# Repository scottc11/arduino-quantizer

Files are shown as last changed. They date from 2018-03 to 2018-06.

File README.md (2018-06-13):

## LIBRARIES / DEPENDENCIES

#### [Adafruit MPR121](https://learn.adafruit.com/adafruit-mpr121-12-key-capacitive-touch-sensor-breakout-tutorial/overview)
- [eagle files can be found here](https://learn.sparkfun.com/tutorials/mpr121-hookup-guide)
#### [MCP4725 DAC](https://www.adafruit.com/product/935)

---
## QUANTIZER LOGIC

The QUANTIZER needs to output a single voltage relative to the last `touched` or `selected` (via voltage input)

The currently active notes will be toggled on / off via the touch sensors.

There is one touch sensor and one toggle switch for each `TONIC`.  Each `TONIC` will have a state equal to `major`, `minor`, `augmented`, and `diminished`. The state of each `TONIC`will be determined by their respective toggle switches.

The `Vout` will be determined depending on which `MODE` the quantizer is in:

`OUT MODE`: The last touched sensor
  - does not require `Vin`

`ARP MODE`:
  - the 'quantized' `Vin`
  - LEDs represent active notes `Vin` should be quantized to
  - does require `Vin`

Modular synths tend to follow a scheme were a specific change in voltage – such as 1.00 volts – results in a precisely one octave change in pitch. In a 1 volt per octave scheme, 1/12 of a volt change results in a semitone change in pitch.

```
5.00v == 5 octaves == 4095
1.00v == 1 octave == 819
0.08333v == half-tone == 68.25
0.16666v == whole-tone == 136.5
```

MCP4725 Library accepts input as a uint_t value between  0 to 4095

```
I    --> 1.0v ------>  819
II   --> 1.16666v -->  955.5
III  --> 1.33332v -->  1092
IV   --> 1.41665v -->  1160.25
V    --> 1.58331v -->  1296.75
VI   --> 1.74997v --> 1433.25
VII  --> 1.91663v --> 1569.75
VIII --> *2.0v    --> 1638

* round up to make perfect octave
```

### Quantization of `Vin` to `activeNotes`:
divide number of activeTonics by 1023. This will give you the thresholds for each note. Copy these thresholds to an array, from lowest to highest.
```

int activeCount = 0;
int activeNotes[];
int thresholdArray[];

for (int i=0; i<arrLength; i++) {
  if (activeTonics[i] == true) {
    activeNotes[activeCount] = quantizedVoltages[i];
    activeCount += 1;
  }
}
int threshold = 1023 / activeCount;
for (int i=0; i<activeCount; i++) {
  thresholdArray[i] = threshold * (i + 1);
}

for (int i=0; i<activeCount; i++) {
  if (Vin < thresholdArray[i]) {
    Vout = activeNotes[i];
  }
}
```

### Moog Werkstatt Calibration

Connect `Vout` of quantizer into the `VCO EXP IN` on the moog werkstatt.  You will have to remove the front panel of the werkstatt and modify the trimmer labelled `VCO EXP TRIM` so that 1.0v and 2.0v coming from `Vout` will make a perfect octave.  Use a tuner for this calibration.

---
# Arduino Programming Practices

#### Things to Note:
- Arduino code is essentially C/C++
- using dictionaries is pretty much out of the question due to memory limits

#### constants vs variables

constants don't take up valuable RAM space (the pre-processor subs the values in where needed), whereas variable declarations do.

```
// constants
#define VALUE_A 3
#define VALUE_B 1

// variables
int value_a = 3;
int value_b = 1;
```

#### [Charlieplexing](https://en.wikipedia.org/wiki/Charlieplexing)
- LED matrix
- Toggle Switch Matrix

---

# [I2C](https://learn.sparkfun.com/tutorials/i2c)

- I2C requires a mere two wires, like asynchronous serial, but those two wires can support up to 1008 slave devices.
- most I2C devices can communicate at 100kHz or 400kHz.
- It can be fairly trivially implemented in software.

#### Signals
- Each I2C bus consists of two signals: SCL and SDA. SCL is the clock signal, and SDA is the data signal.

---

# [Bitwise Operators](https://www.arduino.cc/reference/en/language/structure/bitwise-operators/bitwiseand/)
- One of the most common uses of bitwise AND is to select a particular bit (or bits) from an integer value, often called masking.
- [BitMath Tutorial](http://playground.arduino.cc/Code/BitMath)

In Arduino, the type int is a 16-bit value, so using & between two int expressions causes 16 simultaneous AND operations to occur.

```
int a =  92;    // in binary: 0000000001011100
int b = 101;    // in binary: 0000000001100101
int c = a & b;  // result:    0000000001000100, or 68 in decimal.
```
Each of the 16 bits in `a` and `b` are processed by using the bitwise AND, and all 16 resulting bits are stored in `c`, resulting in the value `01000100` in binary, which is `68` in decimal.

#### Common Bitwise Uses
- Saving memory by packing up to 8 true/false data values in a single byte.
- Turning on/off individual bits in a control register or hardware port register.
- Performing certain arithmetic operations involving multiplying or dividing by powers of 2.

###### Bitwise NOT operator

Bitwise NOT changes each bit to its opposite: 0 becomes 1, and 1 becomes 0. For example:
```
int a = 103;    // binary:  0000000001100111
int b = ~a;     // binary:  1111111110011000 = -104
```

###### Bit Shift Operators --> `>>` or `<<`
There are two bit shift operators in C++: the left shift operator `<<` and the right shift operator `>>`. These operators cause the bits in the left operand to be shifted left or right by the number of positions specified by the right operand. For example:
```
int a = 5;        // binary: 0000000000000101
int b = a << 3;   // binary: 0000000000101000, or 40 in decimal
int c = b >> 3;   // binary: 0000000000000101, or back to 5 like we started with
```
When you shift a value x by y bits (x << y), the leftmost y bits in x are lost, literally shifted out of existence.

### Port registers of the Atmega8

```
void setup()
{
  // set pins 1 (serial transmit) and 2..7 as output,
  // but leave pin 0 (serial receive) as input
  // (otherwise serial port will stop working!) ...
  DDRD = B11111110;  // digital pins 7,6,5,4,3,2,1,0

  // set pins 8..13 as output...
  DDRB = B00111111;  // digital pins -,-,13,12,11,10,9,8

  // Turn off digital output pins 2..7 ...
  PORTD &= B00000011;   // turns off 2..7, but leaves pins 0 and 1 alone

  // Write simultaneously to pins 8..13...
  PORTB = B00111000;   // turns on 13,12,11; turns off 10,9,8
}
```

Sometimes you might need to set multiple output pins at exactly the same time. Calling `digitalWrite(10,HIGH);` followed by `digitalWrite(11,HIGH);` will cause pin 10 to go `HIGH` several microseconds before pin 11, which may confuse certain time-sensitive external digital circuits you have hooked up. Alternatively, you could set both pins high at exactly the same moment in time using `PORTB |= B1100;`

------

### Button / Switch Logic

###### [Polling vs interrupts](http://www.martyncurrey.com/switching-things-on-and-off-with-an-arduino/)

<b>`Polling`</b> is where we are always checking the status of something. Inside the `loop()` function we continuously check the pin state with digitalRead(). We do not know if the pin state has changed until we look at it.

`Interrupts` is where the current process is interrupted and a new process is performed (the Arduino reacts to a pin state whether or not it is being checked). This means the code does not need to worry about the pin until the Arduino tells us to.

##### Turn LED On/Off with push button

```
int previousButtonState = LOW;

void loop() {
  int currentButtonState = cap.touched() & (1 << 0);

  if (currentButtonState == HIGH && oldButtonState == LOW) {
    // Switch the state of the output
    digitalWrite(ledPins[0], !digitalRead(ledPins[0]) );
  }

  previousButtonState = currentButtonState;
}
```

---

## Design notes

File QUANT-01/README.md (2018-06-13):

### Components

- [SPDT Toggle Switch](https://www.digikey.ca/product-detail/en/e-switch/200MSP1T1B1M2QEH/EG2447-ND/378916)
- Arduino Pro Mini
- MPR121 Touch Matrix
- MCP4725 DAC
- LED x 8

# MODES

- when switching between modes, you have to somehjow preserve the previous modes active notes
- one way to do this is to store monophonic mode last touched Vout in a variable, and arpeggiator modes last count + active notes.

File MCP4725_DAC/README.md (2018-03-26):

## [MCP4725 DAC](https://www.adafruit.com/product/935)

- [tutorial](https://learn.adafruit.com/mcp4725-12-bit-dac-tutorial)
- The output voltage is rail-to-rail and proportional to the power pin so if you run it from 3.3V, the output range is 0-3.3V. If you run it from 5V the output range is 0-5V.

#### Wiring

- connect `VDD` to your microcontroller power pin (3-5V), `GND` to ground, `SDA` to I2C Data (on the Arduino Uno, this is `A4`), `SCL` to I2C Clock(on the Arduino Uno, this is `A5`) and listen on `VOUT`.

- `A0` allows you to change the I2C address. By default (nothing attached to A0) the address is hex `0x62`. If `A0` is connected to `VDD` the address is `0x63`.
- `VOUT` is the voltage out from the DAC! The voltage will range from 0V (when the DAC value is 0) to VDD (when the DAC 'value' is the max 12-bit number: `0xFFF`)

---

#### [Adafruit MCP4725 Library](https://github.com/adafruit/Adafruit_MCP4725)

There is only one function that comes with the Adafruit MCP4725 Library, and it is pretty strait forward. In works with Arduino's `Wire` library so you must also import that at the top.

Essentially the function accepts a number between `0` and `4095` which gets evaluated into the Voltage out.  So passing `2500` will give you exactly `3.14V` on the `Vout` pin of the DAC.

```
/**************************************************************************/
/*!
   @brief  Sets the output voltage to a fraction of source vref.  (Value
           can be 0..4095)
   @param[in]  output
               The 12-bit value representing the relationship between
               the DAC's input voltage and its output voltage.
   @param[in]  writeEEPROM
               If this value is true, 'output' will also be written
               to the MCP4725's internal non-volatile memory, meaning
               that the DAC will retain the current voltage output
               after power-down or reset.
*/
/**************************************************************************/

void Adafruit_MCP4725::setVoltage( uint16_t output, bool writeEEPROM )
{
#ifdef TWBR
 uint8_t twbrback = TWBR;
 TWBR = ((F_CPU / 400000L) - 16) / 2; // Set I2C frequency to 400kHz
#endif
 Wire.beginTransmission(_i2caddr);
 if (writeEEPROM)
 {
   Wire.write(MCP4726_CMD_WRITEDACEEPROM);
 }
 else
 {
   Wire.write(MCP4726_CMD_WRITEDAC);
 }
 Wire.write(output / 16);                   // Upper data bits          (D11.D10.D9.D8.D7.D6.D5.D4)
 Wire.write((output % 16) << 4);            // Lower data bits          (D3.D2.D1.D0.x.x.x.x)
 Wire.endTransmission();
#ifdef TWBR
 TWBR = twbrback;
#endif
}
```

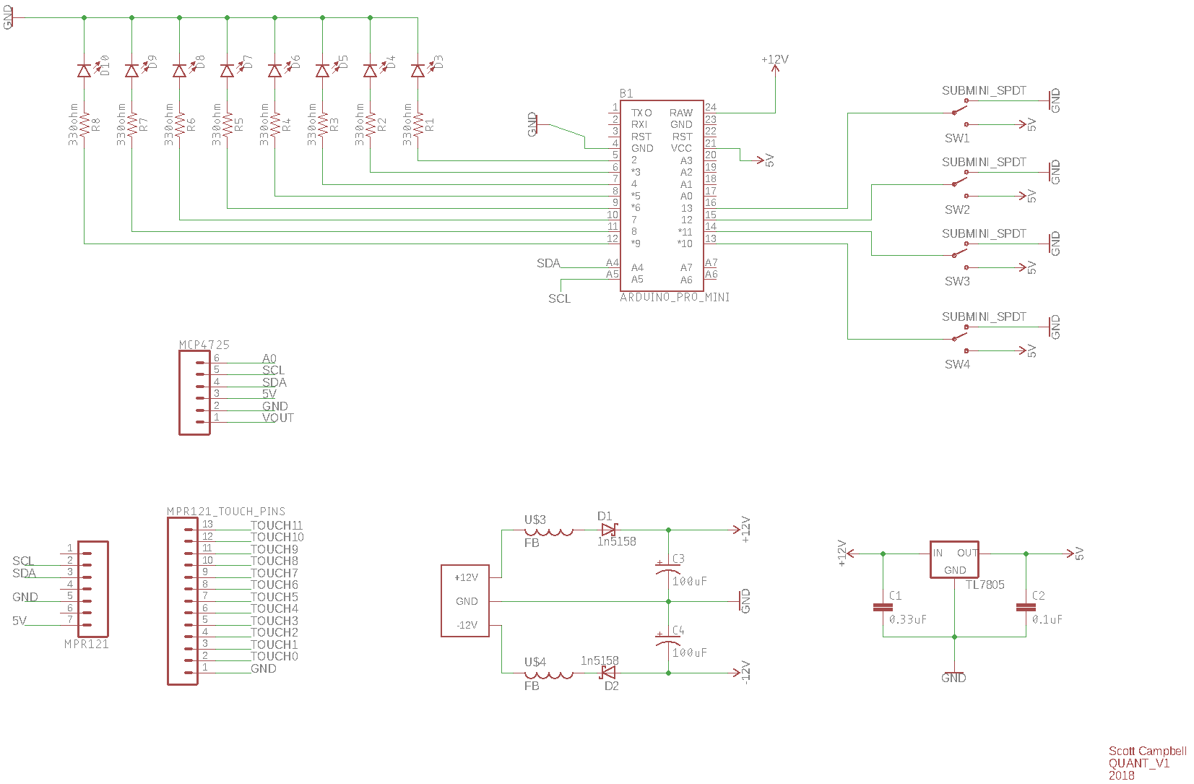
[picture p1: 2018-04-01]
QUANT-01/quant_v1.png

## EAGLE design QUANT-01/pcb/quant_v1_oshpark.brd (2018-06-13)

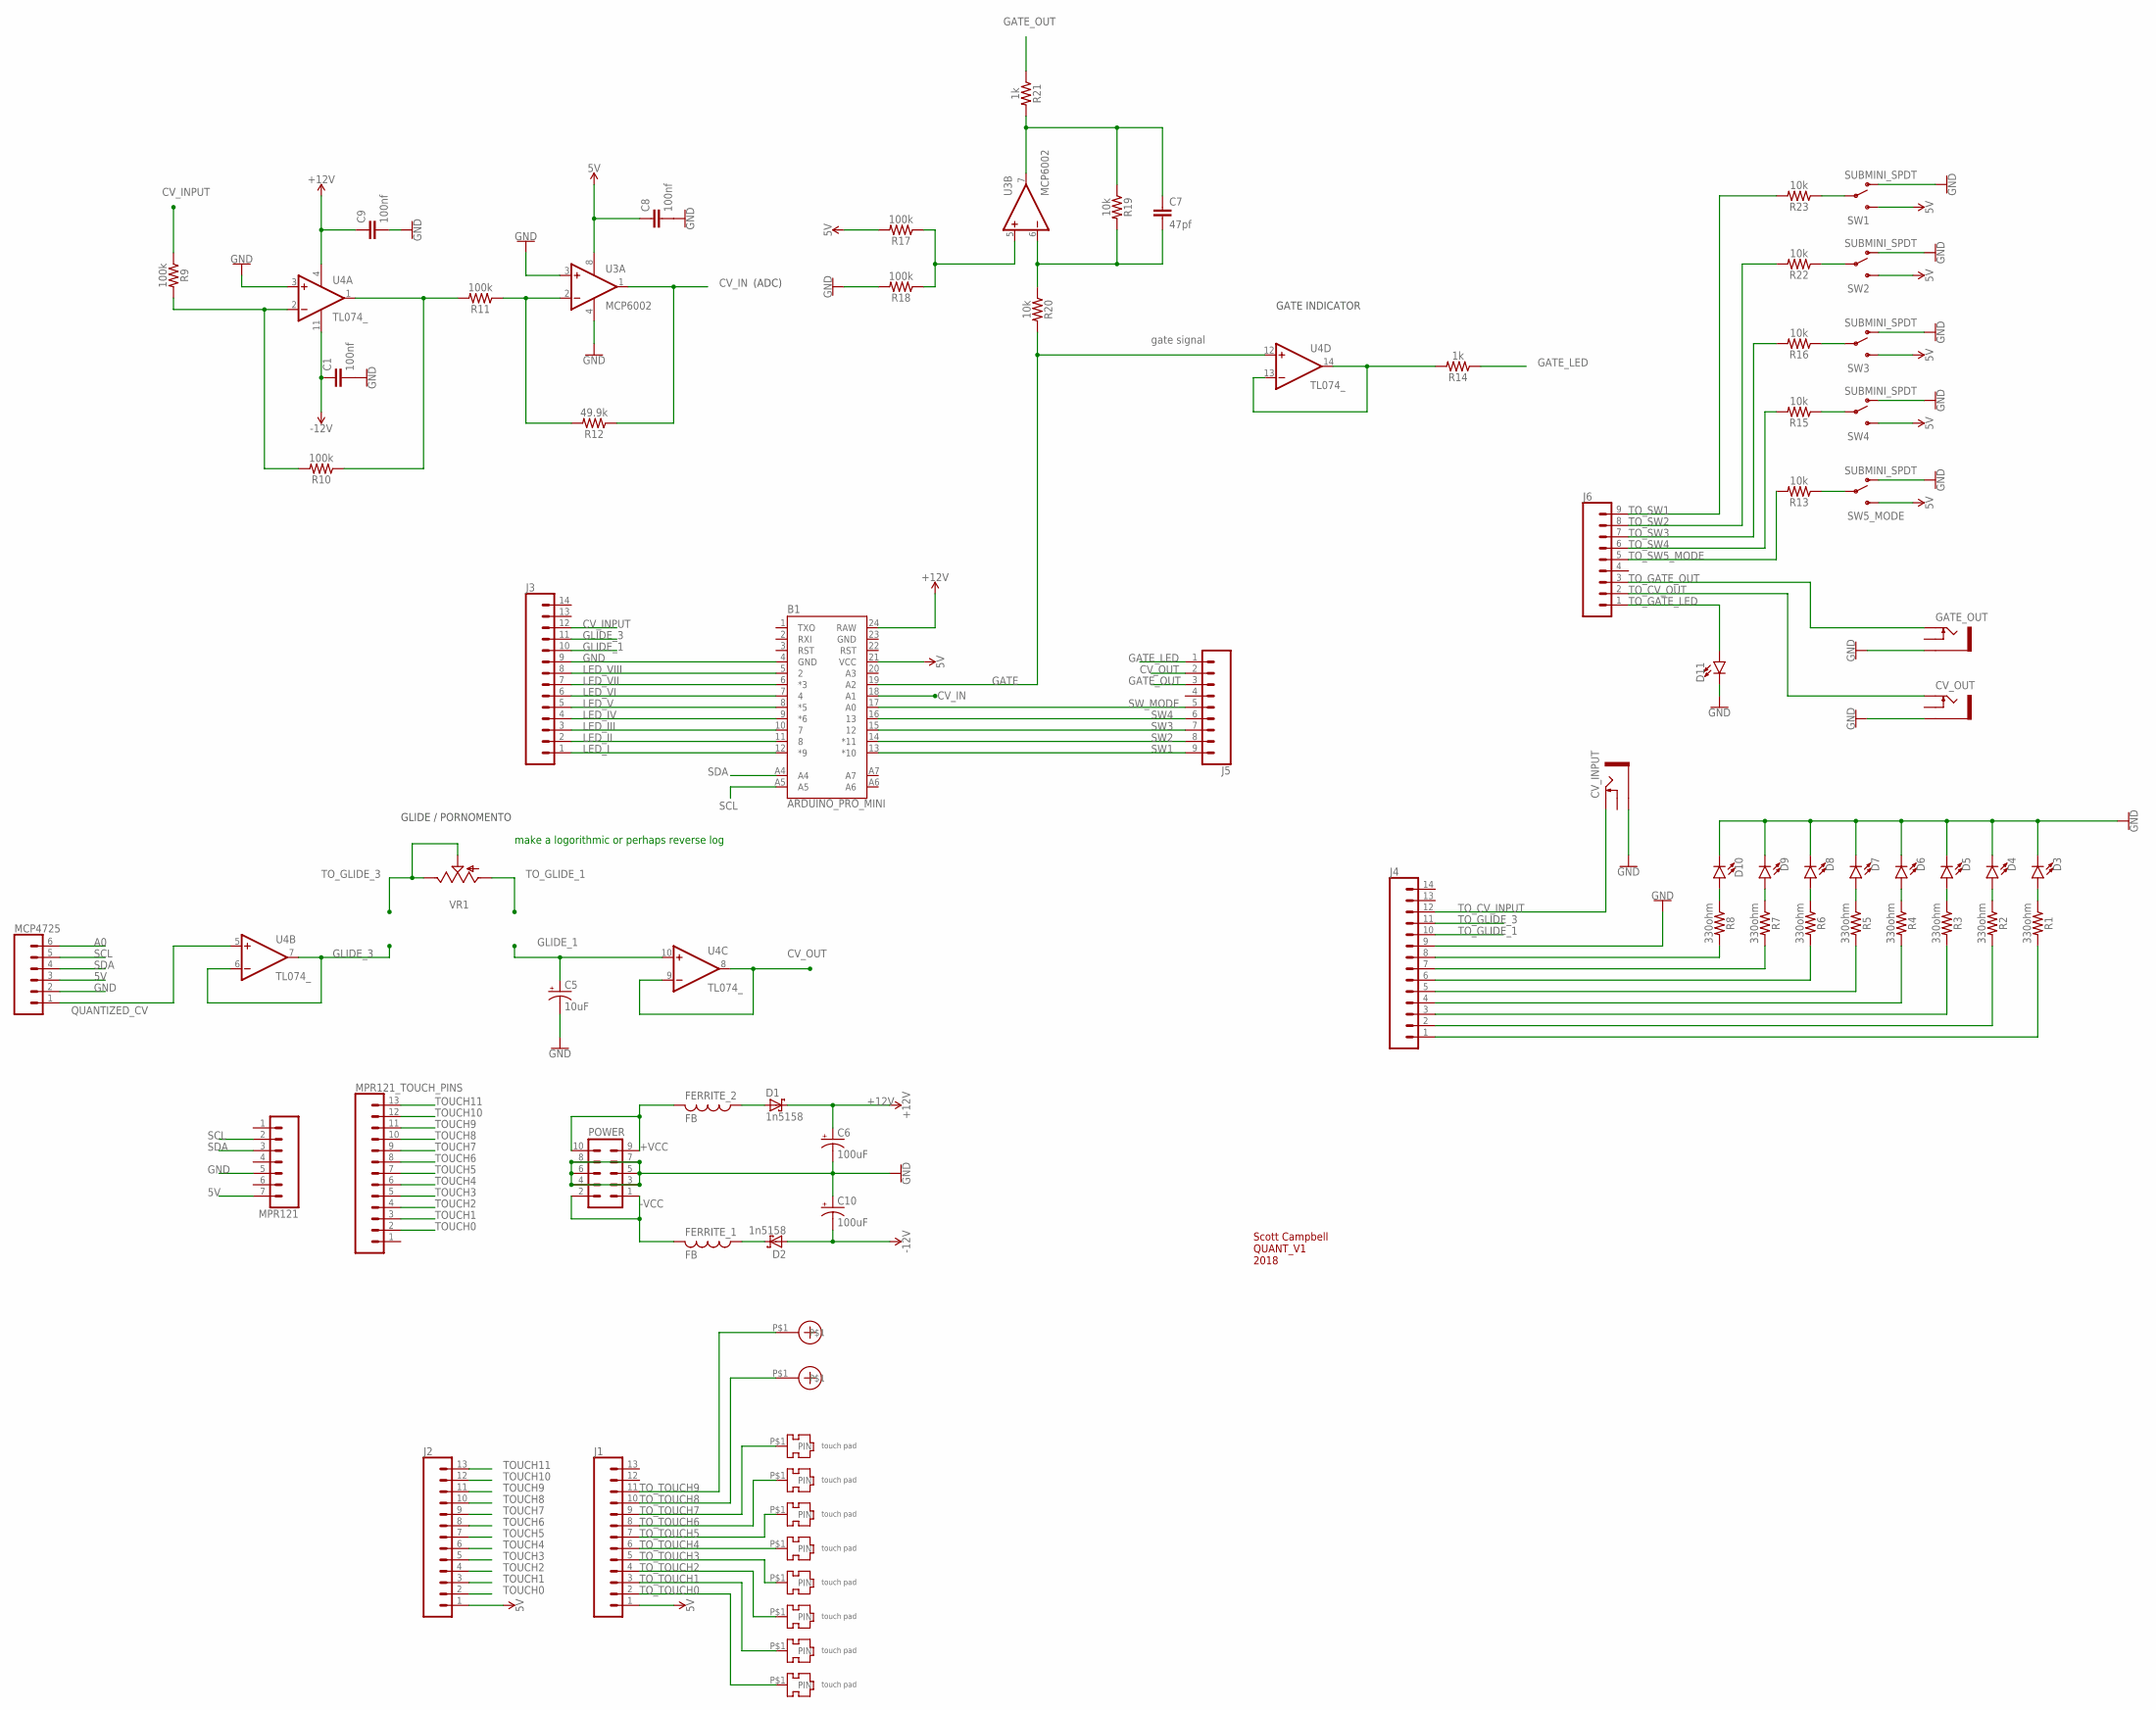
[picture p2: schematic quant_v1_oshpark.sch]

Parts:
B1: ARDUINO_PRO_MINI
C1, C9: 100nf; C2.5-5
C5: 10uF; CPOL-RADIAL-2.5MM-5MM
C6, C10: 100uF; CPOL-RADIAL-2.5MM-6.5MM
C7: 47pf; C2.5-5
C8: 100nf; C2.5-3
CV_INPUT: THONKICONNNEW; WQP-PJ301M-12_JACK
CV_OUT: CV_OUT; WQP-PJ301M-12_JACK
D1, D2: 1n5158; DO41-10
D3, D4, D5, D6, D7, D8, D9, D10, D11: LED3MM; LED_3MM
FERRITE_1, FERRITE_2: FB
GATE_OUT: GATE_OUT; WQP-PJ301M-12_JACK
J1, J2: CONN_13; 1X13
J3, J4: CONN_14; 1X14
J5, J6: CONN_09; 1X09
MCP4725: CONN_06NO_SILK_FEMALE_PTH; 1X06_NO_SILK
MPR121: CONN_07; 1X07
MPR121_TOUCH_PINS: CONN_13; 1X13
POWER: EURO_POWER_HEADERREGULAR; EURO_POWER_HEADER
R1, R2, R3, R4, R5, R6, R7, R8: 330ohm; AXIAL-0.3
R9, R10, R11, R17, R18: 100k; AXIAL-0.3
R12: 49.9k; AXIAL-0.3
R13, R15, R16, R19, R20, R22, R23: 10k; AXIAL-0.3
R14, R21: 1k; AXIAL-0.3
SW1, SW2, SW3, SW4, SW5_MODE: SUBMINI_SPDT; SUBMINI_TOGGLE
TOUCH_1, TOUCH_2, TOUCH_3, TOUCH_4, TOUCH_5, TOUCH_6, TOUCH_7, TOUCH_8: TOUCH_PAD_ESSY
U3: MCP6002; DIL08
U4: TL074_; DIL14
U$1, U$2: TOUCH_PAD_INCREMENT
VR1: 9MM_SNAP-IN_POT_; 9MM_SNAP-IN_POT

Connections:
5V: B1.21 (VCC), C8.1, J1.1, J2.1, MCP4725.3, MPR121.7, R17.P$2 (2), SW1.3 (S), SW2.3 (S), SW3.3 (S), SW4.3 (S), U3.8 (V+)
+12V: B1.24 (RAW), C6.1 (+), C9.1, D1.C, U4.4 (V+)
+VCC: FERRITE_2.P$2 (2), POWER.9, POWER.10
-12V: C1.1, C10.2 (-), D2.A, U4.11 (V-)
-VCC: FERRITE_1.P$2 (2), POWER.1, POWER.2
A0: MCP4725.6
CV_IN: B1.18 (A1), R12.P$1 (1), U3.1 (OUT)
CV_INPUT: J3.12, R9.P$1 (1)
CV_OUT: J5.2, U4.8 (OUT), U4.9 (-IN)
GATE: B1.19 (A2), R20.P$2 (2), U4.12 (+IN)
GATE_LED: J5.1, R14.P$1 (1)
GATE_OUT: J5.3, R21.P$1 (1)
GLIDE_1: C5.1 (+), J3.10, U4.10 (+IN)
GLIDE_3: J3.11, U4.6 (-IN), U4.7 (OUT)
GND: B1.4 (GND), B1.23 (GND), C1.2, C5.2 (-), C6.2 (-), C8.2, C9.2, C10.1 (+), CV_INPUT.P$3_SLEEVE (SLEEVE), CV_OUT.P$3_SLEEVE (SLEEVE), D3.K (C), D4.K (C), D5.K (C), D6.K (C), D7.K (C), D8.K (C), D9.K (C), D10.K (C), D11.K (C), GATE_OUT.P$3_SLEEVE (SLEEVE), J3.9, J4.9, MCP4725.2, MPR121.5, POWER.3, POWER.4, POWER.5, POWER.6, POWER.7, POWER.8, R18.P$2 (2), SW1.1 (O), SW2.1 (O), SW3.1 (O), SW4.1 (O), SW5_MODE.1 (O), U3.3 (+IN), U3.4 (V-), U4.3 (+IN)
LED_I: B1.12 (*9), J3.1
LED_II: B1.11 (8), J3.2
LED_III: B1.10 (7), J3.3
LED_IV: B1.9 (*6), J3.4
LED_V: B1.8 (*5), J3.5
LED_VI: B1.7 (4), J3.6
LED_VII: B1.6 (*3), J3.7
LED_VIII: B1.5 (2), J3.8
unnamed: D2.C, FERRITE_1.P$1 (1)
unnamed: C7.1, R19.P$1 (1), R21.P$2 (2), U3.7 (OUT)
unnamed: D1.A, FERRITE_2.P$1 (1)
unnamed: R23.P$1 (1), SW1.COM (COMMON)
unnamed: D3.A, R1.P$1 (1)
unnamed: R22.P$1 (1), SW2.COM (COMMON)
unnamed: R16.P$1 (1), SW3.COM (COMMON)
unnamed: R15.P$1 (1), SW4.COM (COMMON)
unnamed: R14.P$2 (2), U4.13 (-IN), U4.14 (OUT)
unnamed: D10.A, R8.P$1 (1)
unnamed: D9.A, R7.P$1 (1)
unnamed: D8.A, R6.P$1 (1)
unnamed: D7.A, R5.P$1 (1)
unnamed: D6.A, R4.P$1 (1)
unnamed: D5.A, R3.P$1 (1)
unnamed: D4.A, R2.P$1 (1)
unnamed: C7.2, R19.P$2 (2), R20.P$1 (1), U3.6 (-IN)
unnamed: R9.P$2 (2), R10.P$2 (2), U4.2 (-IN)
unnamed: R13.P$1 (1), SW5_MODE.COM (COMMON)
unnamed: R10.P$1 (1), R11.P$2 (2), U4.1 (OUT)
unnamed: R11.P$1 (1), R12.P$2 (2), U3.2 (-IN)
unnamed: R17.P$1 (1), R18.P$1 (1), U3.5 (+IN)
unnamed: J4.8, R8.P$2 (2)
unnamed: J4.7, R7.P$2 (2)
unnamed: J4.6, R6.P$2 (2)
unnamed: J4.5, R5.P$2 (2)
unnamed: J4.4, R4.P$2 (2)
unnamed: J4.3, R3.P$2 (2)
unnamed: J4.2, R2.P$2 (2)
unnamed: J4.1, R1.P$2 (2)
QUANTIZED_CV: MCP4725.1, U4.5 (+IN)
SCL: B1.A5, MCP4725.5, MPR121.2
SDA: B1.A4, MCP4725.4, MPR121.3
SW1: B1.13 (*10), J5.9
SW2: B1.14 (*11), J5.8
SW3: B1.15 (12), J5.7
SW4: B1.16 (13), J5.6
SW_MODE: B1.17 (A0), J5.5
TOUCH0: J2.2, MPR121_TOUCH_PINS.2
TOUCH1: J2.3, MPR121_TOUCH_PINS.3
TOUCH2: J2.4, MPR121_TOUCH_PINS.4
TOUCH3: J2.5, MPR121_TOUCH_PINS.5
TOUCH4: J2.6, MPR121_TOUCH_PINS.6
TOUCH5: J2.7, MPR121_TOUCH_PINS.7
TOUCH6: J2.8, MPR121_TOUCH_PINS.8
TOUCH7: J2.9, MPR121_TOUCH_PINS.9
TOUCH8: J2.10, MPR121_TOUCH_PINS.10
TOUCH9: J2.11, MPR121_TOUCH_PINS.11
TOUCH10: J2.12, MPR121_TOUCH_PINS.12
TOUCH11: J2.13, MPR121_TOUCH_PINS.13
TO_CV_INPUT: CV_INPUT.P$1_TIP (TIP), J4.12
TO_CV_OUT: CV_OUT.P$1_TIP (TIP), J6.2
TO_GATE_LED: D11.A, J6.1
TO_GATE_OUT: GATE_OUT.P$1_TIP (TIP), J6.3
TO_GLIDE_1: J4.10, VR1.1 (A)
TO_GLIDE_3: J4.11, VR1.2 (S), VR1.3 (E)
TO_SW1: J6.9, R23.P$2 (2)
TO_SW2: J6.8, R22.P$2 (2)
TO_SW3: J6.7, R16.P$2 (2)
TO_SW4: J6.6, R15.P$2 (2)
TO_SW5_MODE: J6.5, R13.P$2 (2)
TO_TOUCH0: J1.2, TOUCH_8.P$1
TO_TOUCH1: J1.3, TOUCH_7.P$1
TO_TOUCH2: J1.4, TOUCH_6.P$1
TO_TOUCH3: J1.5, TOUCH_5.P$1
TO_TOUCH4: J1.6, TOUCH_4.P$1
TO_TOUCH5: J1.7, TOUCH_3.P$1
TO_TOUCH6: J1.8, TOUCH_2.P$1
TO_TOUCH7: J1.9, TOUCH_1.P$1
TO_TOUCH8: J1.10, U$2.P$1
TO_TOUCH9: J1.11, U$1.P$1

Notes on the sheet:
Scott Campbell QUANT_V1 2018
GLIDE / PORNOMENTO
GATE INDICATOR
gate signal
(ADC)
make a logorithmic or perhaps reverse log

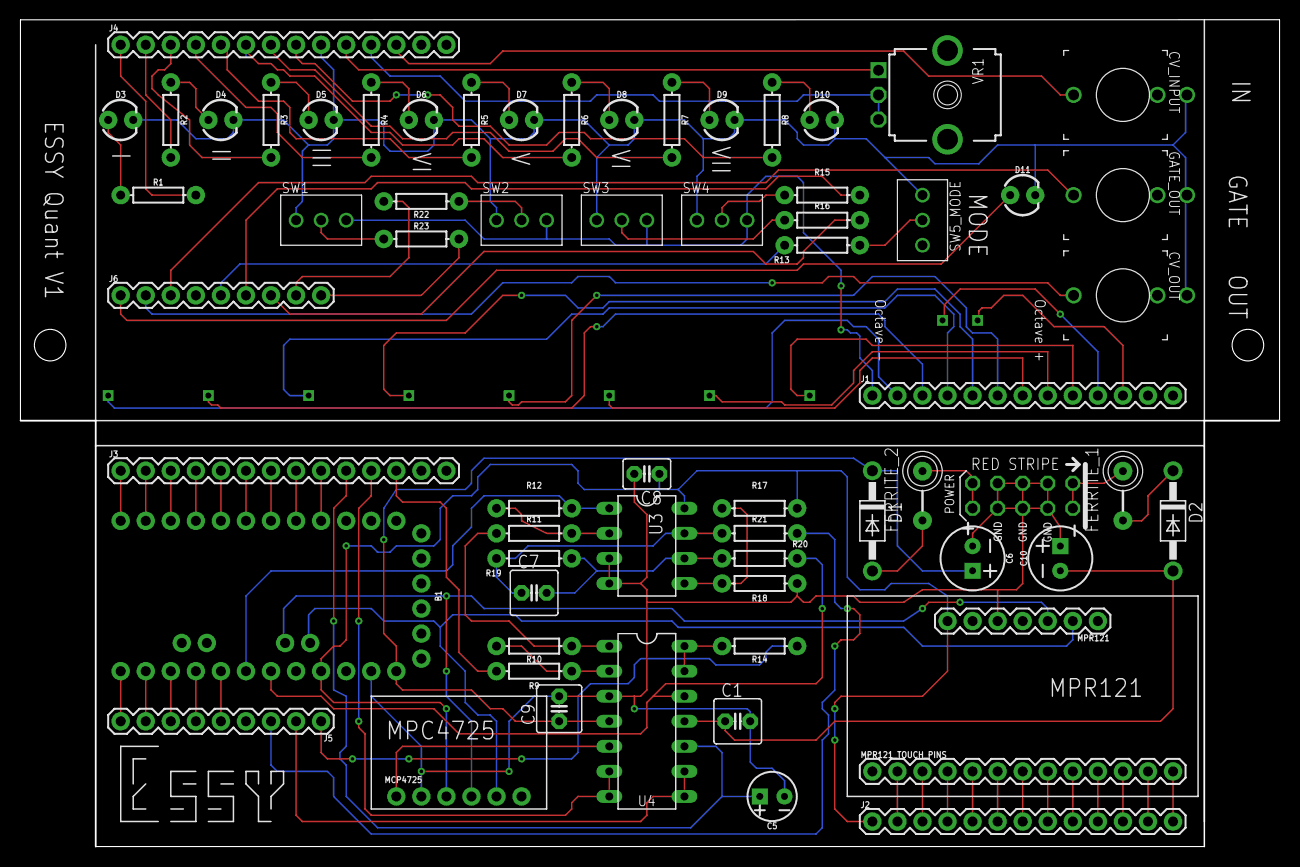
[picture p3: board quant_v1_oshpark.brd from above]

Board: 2 copper layers, 127.6 x 83.8 mm, 77 parts (0 on the bottom side), 93 nets.

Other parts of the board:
U$3, U$4: EURO_PANEL_SCREW_HOLE

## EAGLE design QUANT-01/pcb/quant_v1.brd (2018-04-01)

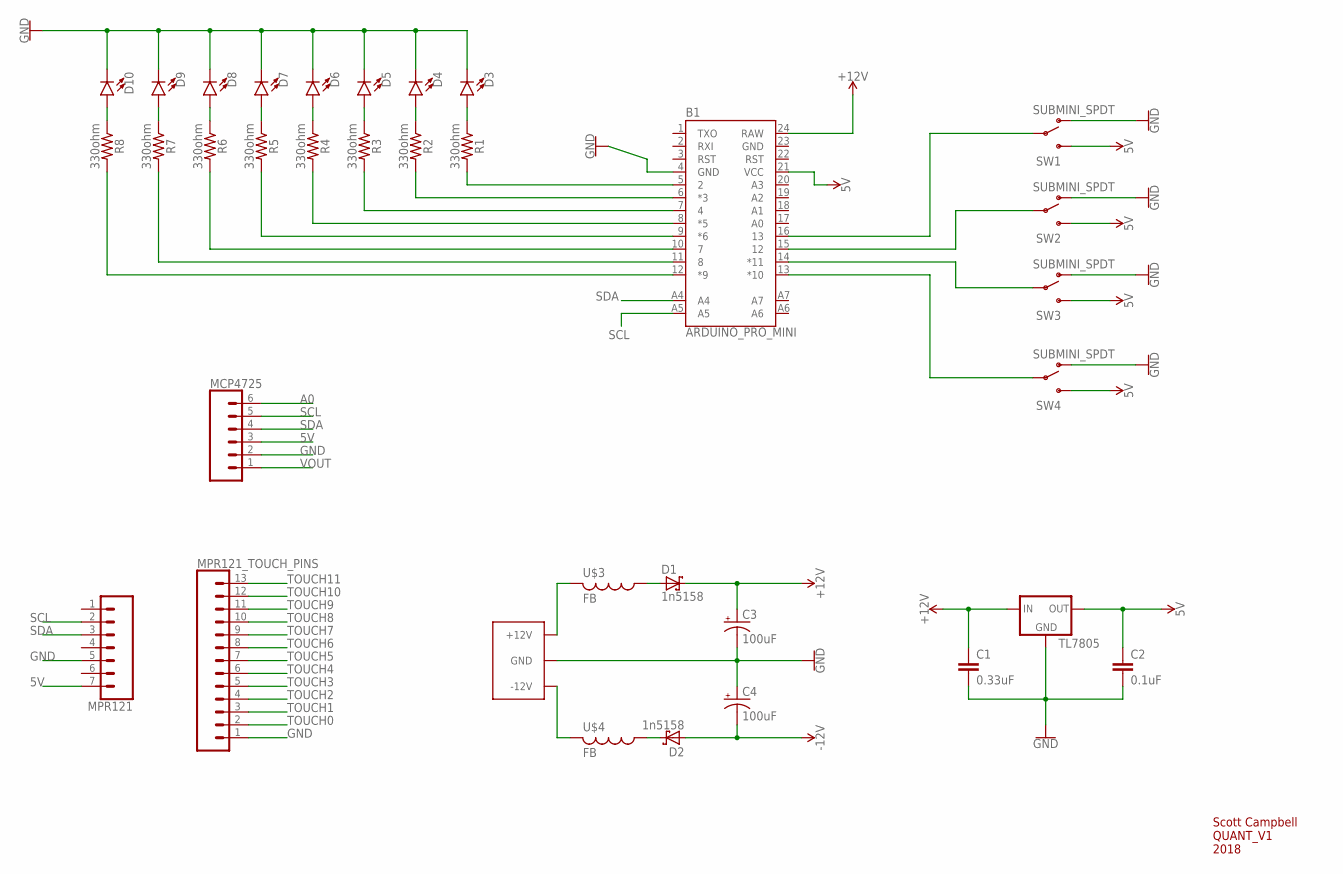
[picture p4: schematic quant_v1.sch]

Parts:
B1: ARDUINO_PRO_MINI
C1: 0.33uF; CAP-PTH-10MM
C2: 0.1uF; CAP-PTH-10MM
C3, C4: 100uF; CPOL-RADIAL-5MM-10MM
D1, D2: 1n5158; DO41-10
D3, D4, D5, D6, D7, D8, D9, D10: LED3MM; LED_3MM
MCP4725: CONN_06NO_SILK_FEMALE_PTH; 1X06_NO_SILK
MPR121: CONN_07; 1X07
MPR121_TOUCH_PINS: CONN_13; 1X13
R1, R2, R3, R4, R5, R6, R7, R8: 330ohm; AXIAL-0.3
SW1, SW2, SW3, SW4: SUBMINI_SPDT; SUBMINI_TOGGLE
TL7805: R-78E5.0-1.0; DC-DC_CONVERTER_78XX
U$1: EURO_POWER_LOCK; EURO_PWR_HEADER_LOCK
U$3, U$4: FB

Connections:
5V: B1.21 (VCC), B1.24 (RAW), C2.1, C3.+, C4.-, D1.C, D2.A, MCP4725.3, MPR121.7, SW1.3 (S), SW2.3 (S), SW3.3 (S), SW4.3 (S), TL7805.VOUT (OUT)
+12V: C1.1, TL7805.VIN (IN)
-12V: U$1.NEG1 (-12V), U$1.NEG2 (-12V), U$4.P$2 (2)
A0: MCP4725.6
GND: B1.4 (GND), B1.23 (GND), C1.2, C2.2, C3.-, C4.+, D3.K (C), D4.K (C), D5.K (C), D6.K (C), D7.K (C), D8.K (C), D9.K (C), D10.K (C), MCP4725.2, MPR121.5, MPR121_TOUCH_PINS.1, SW1.1 (O), SW2.1 (O), SW3.1 (O), SW4.1 (O), TL7805.GND, U$1.GND1 (GND), U$1.GND2 (GND), U$1.GND3 (GND), U$1.GND4 (GND), U$1.GND5 (GND), U$1.GND6 (GND)
unnamed: U$1.POS1 (+12V), U$1.POS2 (+12V), U$3.P$2 (2)
unnamed: D2.C, U$4.P$1 (1)
unnamed: D1.A, U$3.P$1 (1)
unnamed: B1.5 (2), R1.P$2 (2)
unnamed: D3.A, R1.P$1 (1)
unnamed: B1.6 (*3), R2.P$2 (2)
unnamed: B1.7 (4), R3.P$2 (2)
unnamed: B1.8 (*5), R4.P$2 (2)
unnamed: B1.9 (*6), R5.P$2 (2)
unnamed: B1.10 (7), R6.P$2 (2)
unnamed: B1.11 (8), R7.P$2 (2)
unnamed: B1.12 (*9), R8.P$2 (2)
unnamed: D10.A, R8.P$1 (1)
unnamed: D9.A, R7.P$1 (1)
unnamed: D8.A, R6.P$1 (1)
unnamed: D7.A, R5.P$1 (1)
unnamed: D6.A, R4.P$1 (1)
unnamed: D5.A, R3.P$1 (1)
unnamed: D4.A, R2.P$1 (1)
SCL: B1.A5, MCP4725.5, MPR121.2
SDA: B1.A4, MCP4725.4, MPR121.3
SW1: B1.13 (*10), SW4.COM (COMMON)
SW2: B1.14 (*11), SW3.COM (COMMON)
SW3: B1.15 (12), SW2.COM (COMMON)
SW4: B1.16 (13), SW1.COM (COMMON)
TOUCH0: MPR121_TOUCH_PINS.2
TOUCH1: MPR121_TOUCH_PINS.3
TOUCH2: MPR121_TOUCH_PINS.4
TOUCH3: MPR121_TOUCH_PINS.5
TOUCH4: MPR121_TOUCH_PINS.6
TOUCH5: MPR121_TOUCH_PINS.7
TOUCH6: MPR121_TOUCH_PINS.8
TOUCH7: MPR121_TOUCH_PINS.9
TOUCH8: MPR121_TOUCH_PINS.10
TOUCH9: MPR121_TOUCH_PINS.11
TOUCH10: MPR121_TOUCH_PINS.12
TOUCH11: MPR121_TOUCH_PINS.13
VOUT: MCP4725.1

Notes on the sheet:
Scott Campbell QUANT_V1 2018

Board: 2 copper layers, 34 parts (0 on the bottom side), 29 nets, no tracks yet.

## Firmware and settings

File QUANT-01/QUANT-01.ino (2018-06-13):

#include <Wire.h>
#include <Adafruit_MCP4725.h>
#include <Adafruit_MPR121.h>

// You can have up to 4 on one i2c bus but one is enough for testing!
Adafruit_MPR121 cap = Adafruit_MPR121();

Adafruit_MCP4725 dac;

// CONSTANTS
int LENGTH = 8; // length of arrays


// TONICS


// VOLTAGE INPUT/OUTPUT
int VinPin = A1;    // Voltage Input Pin
int Vin = 0;        // Variable to store value of VinPin
int Vout = 0;       // quantized voltage output

// MODE
int MODE_PIN = A0;   // toggles QUANTIZER_MODE variable true/false
bool newModeSwitchState = 0;
bool oldModeSwitchState = 0;
bool QUANTIZER_MODE = false;

int GATE_PIN = A2;
int OCTAVE_UP_PIN = 9;
int OCTAVE_DOWN_PIN = 8;

// Keeps track of the last pins touched
uint16_t lasttouched = 0;
uint16_t currtouched = 0;

// Toggle Switches
int switchPins[] = {0, 0, 10, 0, 11, 12, 13, 0};

// variables to hold bitmask values of switch states. These will essentially be the equivalent of an array containing 
// 8 integers with the values of 0 or 1. Use bitRead(newSwitchStates, index) to get the value of a bit
byte newSwitchStates = 0;
byte oldSwitchStates = 0;


int ledPins[] = {9, 8, 7, 6, 5, 4, 3, 2}; // LED pins: they are backwards order because I'm a goof.
int OCTAVE = 0;
int OCTAVE_VALUES[] = {0, 819, 1638, 2457, 3276};

int quantizedVoltages[8][2] = {
    { 0, 0 }, // I
    { 136.5, 0 },
    { 204.75, 273 },   // min3, maj3
    { 341.25, 409.5 }, // per4, aug4
    { 409.5, 477.75 }, // dim5, per5
    { 546, 614.25 },   // min6, maj6
    { 682.5, 750.75 }, // min7, maj7
    { 819, 0 } // VIII
  };

bool activeQuantizedNotes[] = {0, 0, 0, 0, 0, 0, 0, 0};
bool activeMonophonicNotes[] = {0, 0, 0, 0, 0, 0, 0, 0};
int lastTouchedIndex = 0;  // Needed specifically for monophonic notes when toggleing tonic switches

int activeCount = 0;   // how many notes are active/selected (0 === 1 active note)
int activeVoltages[8]; // active quantized voltages (from low to high)
int thresholdArray[8]; // int representation of Vin mapped to activeVoltages



// mapping Vin to a Vout in activeVoltages
void setActiveVoltageThresholds(int count) {
  int threshold = 1023 / count;
  for (int i=0; i<count; i++) {
    thresholdArray[i] = threshold * (i + 1);
  }
}


// -----------------------------------
// SET ACTIVE NOTES FOR Vout
// -----------------------------------
void setActiveVoltages() {
  activeCount = 0;
  for (int i=0; i<LENGTH; i++) {                              
    if (activeQuantizedNotes[i] == true) {
      uint8_t state = bitRead(newSwitchStates, i);
      activeVoltages[activeCount] = quantizedVoltages[i][state];
      activeCount += 1;
    }
  }
  setActiveVoltageThresholds(activeCount);
}


// -----------------------------------
// SET VOLTAGE OUT
//   - final stage determining which voltage to set the DAC too
// -----------------------------------
void setVoltageOut(int index) {
  if (QUANTIZER_MODE) {
    Vin = analogRead(VinPin);
    for (int i=0; i<activeCount; i++) {
      if (Vin < thresholdArray[i]) {
        Vout = activeVoltages[i] + OCTAVE_VALUES[OCTAVE]; // state not needed here, see --> setActiveVoltages()
  
        // Set quantized voltage output
        dac.setVoltage(Vout, false);
        break;
      }
      delay(1);
    }
  } else {
    uint8_t state = bitRead(newSwitchStates, index);
    Vout = quantizedVoltages[index][state] + OCTAVE_VALUES[OCTAVE];
    dac.setVoltage(Vout, false); // Set quantized voltage output
  }
}


// -----------------------------------
// SET ACTIVE NOTES
// - based on current mode of quantizer, set the 'active' notes based on user selection via touch pads
// note: this is not setting the voltage!
// -----------------------------------
void setActiveNotes(int index) {
  if (QUANTIZER_MODE) {
    // activate / deactivate notes
    // activeNotes[index] = !activeNotes[index];

    activeQuantizedNotes[index] = !activeQuantizedNotes[index];
    
    // toggle digital pin state (LEDs) based on active/inactive notes
    digitalWrite(ledPins[index], activeQuantizedNotes[index]);

    setActiveVoltages();
  }
  else {
    // set last pressed note HIGH and reset all others to LOW
    for (int i=0; i<LENGTH; i++) {
      if (i == index) {
        activeMonophonicNotes[i] = HIGH;
        lastTouchedIndex = i;
        setVoltageOut(lastTouchedIndex);
      } else {
        activeMonophonicNotes[i] = LOW;
      }
      digitalWrite(ledPins[i], activeMonophonicNotes[i]);
    }
  }
  
}



// -----------------------------------
// SET/TOGGLE MODE
// -----------------------------------
void toggleMode(bool switchState) {
  QUANTIZER_MODE = switchState;

  if (QUANTIZER_MODE) {
    for (int i=0; i<LENGTH; i++) {
      // toggle digital pin state (LEDs) based on active/inactive notes
      digitalWrite(ledPins[i], activeQuantizedNotes[i]);
      setActiveVoltages();
    }
    
  } else {
    for (int i=0; i<LENGTH; i++) {
      // toggle digital pin state (LEDs) based on active/inactive notes
      digitalWrite(ledPins[i], activeMonophonicNotes[i]);
      if (activeMonophonicNotes[i] == HIGH) {
        setVoltageOut(i);
      }
    }
  }
}



// -----------------------------------
// SET OCTAVE
// -----------------------------------
void setOctave(int BUTTON) {
  if (BUTTON == OCTAVE_UP_PIN) {
    if (OCTAVE < 4) {
      OCTAVE += 1;
    }
  }
  else if (BUTTON == OCTAVE_DOWN_PIN) {
    if (OCTAVE > 0) {
      OCTAVE -= 1;
    }
  }
  
}





// ==============================================================================================================
// SETUP
// ==============================================================================================================

void setup() {
  Serial.begin(9600);

  // Connect MPR121 touch sensors @ I2C address 0x5A (default)
  if (!cap.begin(0x5A)) {
    Serial.println("MPR121 not found, check wiring?");
    while (1);
  }
  Serial.println("MPR121 found!");

  // Connect MCP4725A1 DAC @ I2C address 0x62 (default)
  dac.begin(0x62);

  // Set pinouts for LEDs
  for(int p=0; p<LENGTH; p++) {
    pinMode(ledPins[p], OUTPUT); // Set the mode to OUTPUT
  }
  // Set pinouts for toggle Switches
  pinMode(13, INPUT);
  pinMode(12, INPUT);
  pinMode(11, INPUT);
  pinMode(10, INPUT);```````````````````````````````````````````````````````````
  
  // A1 acting as digitalInput
  pinMode(MODE_PIN, INPUT_PULLUP);
  toggleMode(digitalRead(MODE_PIN));

  pinMode(GATE_PIN, OUTPUT);
  digitalWrite(GATE_PIN, HIGH);

}






// ==============================================================================================================
// LOOP
// ==============================================================================================================

void loop() {
  
  // Get the currently touched pads
  // cap.touched will return 16 bits (one byte), with each bit (from 0 - 12) representing the corrosponding touch pad
  currtouched = cap.touched();

  newModeSwitchState = digitalRead(MODE_PIN);

  if (newModeSwitchState != oldModeSwitchState) {
    Serial.print("Switching MODE to: "); Serial.println(newModeSwitchState);
    oldModeSwitchState = newModeSwitchState;
    toggleMode(newModeSwitchState);
  }



  // get switch states of each scale step
  for (uint8_t i=0; i < 8; i++) {
    if (i == 2 || i == 4 || i == 5 || i == 6) {
      uint8_t state = digitalRead(switchPins[i]);
      bitWrite(newSwitchStates, i, state);
    }
  }
  
  if ( newSwitchStates != oldSwitchStates ) {
    oldSwitchStates = newSwitchStates;
    setActiveVoltages();
    if (!QUANTIZER_MODE) {
      setVoltageOut(lastTouchedIndex);
    }
  }
  


  // Iterate over touch sensors
  for (uint8_t i=0; i<12; i++) {

    // BUTTON TOUCHED
    // if it *is* touched and *wasnt* touched before, alert!
    if ( (currtouched & _BV(i) ) && !( lasttouched & _BV(i) ) ) {
      Serial.print(i); Serial.print(" touched :: "); Serial.println(i, BIN);
      
      if (i < 8) {
        digitalWrite(GATE_PIN, HIGH); // SET GATE HIGH (opposite via schmitt trigger)
        setActiveNotes(i); 
      }
      else if (i > 7) {
        setOctave(i);
      }

    }



    // BUTTON RELEASED
    //  if it *was* touched and now *isnt*, alert!
    if (!(currtouched & _BV(i)) && (lasttouched & _BV(i)) ) {

      
      digitalWrite(GATE_PIN, LOW); // SET GATE LOW

      Serial.print(" .             OCTAVE -->   ");
      Serial.println(OCTAVE);
      
      Serial.print(" .    active voltages -->   ");
      for (int i=0; i<LENGTH; i++) {
        Serial.print(activeVoltages[i]); Serial.print(" : ");
      }

      Serial.println("");
      Serial.print("Voltage IN thresholds -->   ");
      for (int i=0; i<LENGTH; i++) {
        Serial.print(thresholdArray[i]); Serial.print(" : ");
      }

      Serial.println("");
      Serial.print("  active tonics count -->   "); Serial.println(activeCount);

//      Serial.print(i); Serial.println(" released");
    }
  }

  // reset touch sensors state
  lasttouched = currtouched;

  // if in quantizer mode apply Vout based on Vin
  if (QUANTIZER_MODE) {
    setVoltageOut(0);
  }
}

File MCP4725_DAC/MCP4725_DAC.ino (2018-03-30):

/*!
 * Modular synths tend to follow a scheme were a specific change in voltage – 
 * such as 1.00 volts – results in a precisely one octave change in pitch. In a 
 * 1 volt per octave scheme, 1/12 of a volt change results in a semitone change in pitch.
 * 
 * 5.00v == 5 octaves
 * 1.00v == 1 octave
 * 0.08333V == 1 step
 * 
 * MCP4725 Library
 * input == 0 .. 4095
 * 
 * 1 octave == 819
 * 1 step = 68.25 
 * 
*/



#include <Wire.h>
#include <Adafruit_MCP4725.h>

Adafruit_MCP4725 dac;

void setup() {
  Serial.begin(9600);

  // For Adafruit MCP4725A1 the address is 0x62 (default) or 0x63 (ADDR pin tied to VCC)
  dac.begin(0x62);
  
}

void loop() {

  uint16_t output = 819;

  for (uint16_t i=68.25; i<4095; i=i+68.25) {
    Serial.println(i);
    dac.setVoltage(i, false);
    delay(1000);
  }
}

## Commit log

2018-03-29 DAC is now outputting proper voltages per semitone
2018-03-30 setup base quantizer arduino sketch.
2018-03-30 implemented the tonic scale system using set values for voltages of a major scale.
2018-03-30 added schematic.
    [schematic-v1.sch]
2018-03-30 kind of got the quantization of Vin working.
    [schematic-v1.sch]
2018-03-30 fixed arpegiator bug causing awfull quantization by adding a break statement
    [QUANT-01.ino]
2018-03-30 successfully added toggle switch states to code allowing for major/minor mods
2018-03-31 added eagle fold pcb. moved schematic file into that new folder. created base perf board file,
    [quant_v1.brd, schematic-v1.sch]
2018-04-01 built the base schematic.
    [quant_v1.brd, quant_v1.sch, schematic-v1.sch]
2018-04-05 switched to new branch.
2018-04-07 fixed tonic switch bug
    [QUANT-01.ino]
2018-04-07 established mode switching while persisting active notes for each mode between switches.
2018-04-08 added simple GATE out code.
    [quant_v1.brd, quant_v1.sch]
2018-04-10 started building board.
    [quant_v1.brd, quant_v1.sch]
2018-04-11 got bottom pcb basic layout in place.
    [quant_v1.brd, quant_v1.sch]
2018-04-12 started wiring.
    [quant_v1.brd, quant_v1.sch]
2018-04-15 starting wiring. completed layout of components.
    [quant_v1.brd, quant_v1.sch]
2018-05-26 completed first PCB run with OSH park. Beginning to make mods to add octaves.
    [quant_v1_oshpark.brd, quant_v1_oshpark.sch]
2018-06-13 fixed formula for increasing / decreasing octave
    [QUANT-01.ino]
2018-06-13 added remaining tonic toggle switches. Switched some pins around to match schematic. Currently a stable build.

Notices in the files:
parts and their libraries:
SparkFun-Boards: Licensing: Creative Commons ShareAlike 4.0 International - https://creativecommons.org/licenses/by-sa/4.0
